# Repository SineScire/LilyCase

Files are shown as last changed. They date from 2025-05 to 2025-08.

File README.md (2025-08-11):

<a href="https://github.com/SineScire/LilyCase">LilyCase</a> © 2025 by <a href="https://github.com/SineScire">SineNomen</a> is licensed under <a href="https://creativecommons.org/licenses/by-nc-sa/4.0/">CC BY-NC-SA 4.0</a>

A tented case for the Lily58 with a gasket mounted switchplate. The Lily58 is originally created by [kata0510](https://github.com/kata0510), the case is made to use with the Lily58L created by [BenRoe](https://github.com/BenRoe).

There are multiple versions of the case
* With magnets: has holes for 6x2mm circular magnets for the palm rest and tag plate, wrist rest is recessed deeper for an additional plate.
* Without magnets: the wrist rest has to be attached with double sided tape or glue, magnet holes for the tag plate are still present.
* The files and directories with the "old" suffix are from the original case design, where the IO for the PCB is rerouted to bottom case housing.

And multiple versions of the gaskets:
* Soft: Switchplate flexes with the press of a single key
* Medium: Switchplate flexes with the press of multiple keys
* Hard: Switchplate hardly flexes with the press of multiple keys

Check out the manual [here](https://github.com/SineScire/LilyCase/blob/a8cb191af96765f0c5e2880e67829a860b818092/Manual.md)

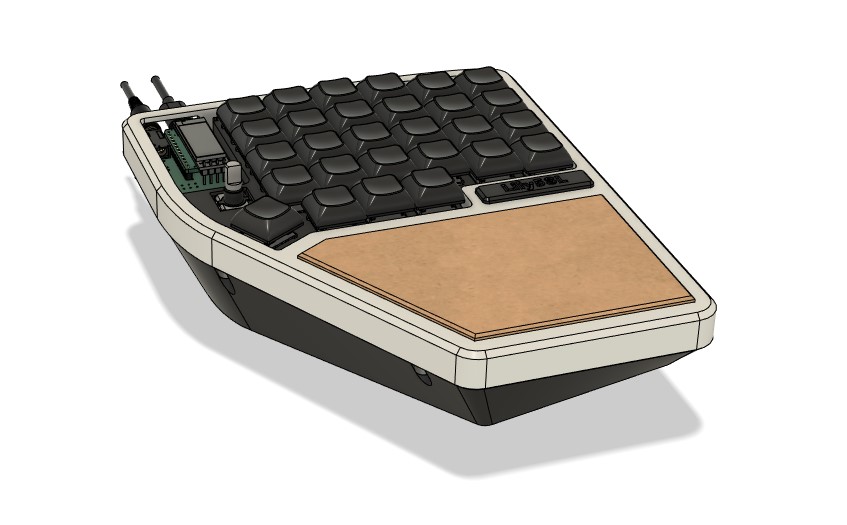
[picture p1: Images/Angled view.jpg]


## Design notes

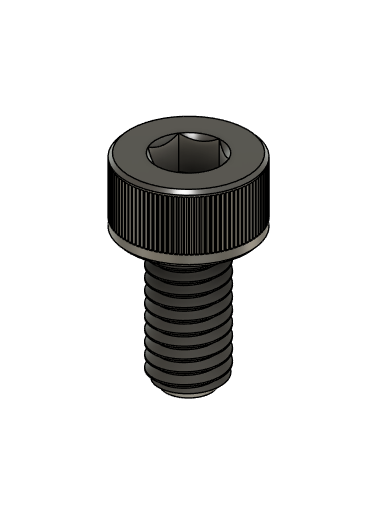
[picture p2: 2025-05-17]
Images/Fastner.png

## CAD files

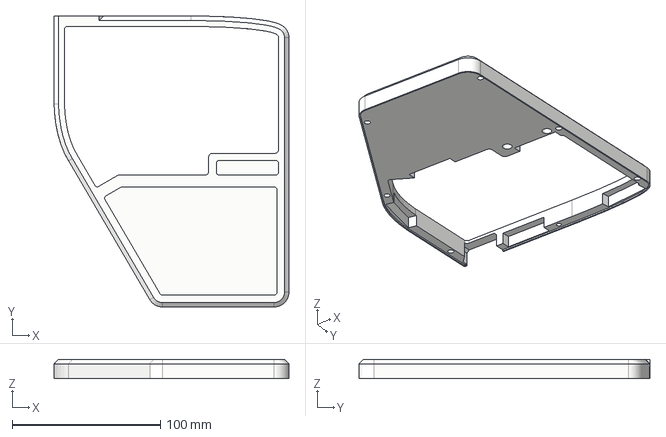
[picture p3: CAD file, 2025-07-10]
Files/TopHousing.step
158.5 x 196.4 x 13.0 mm

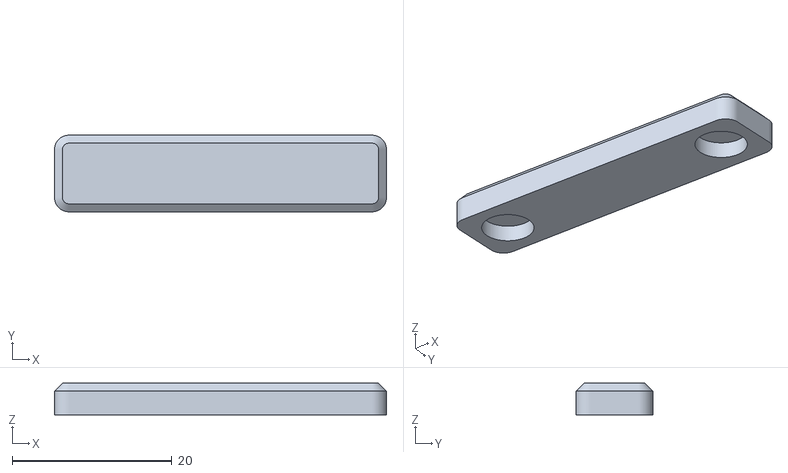
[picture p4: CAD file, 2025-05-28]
Files/TagPlateBlank.obj
41.6 x 9.60 x 4.00

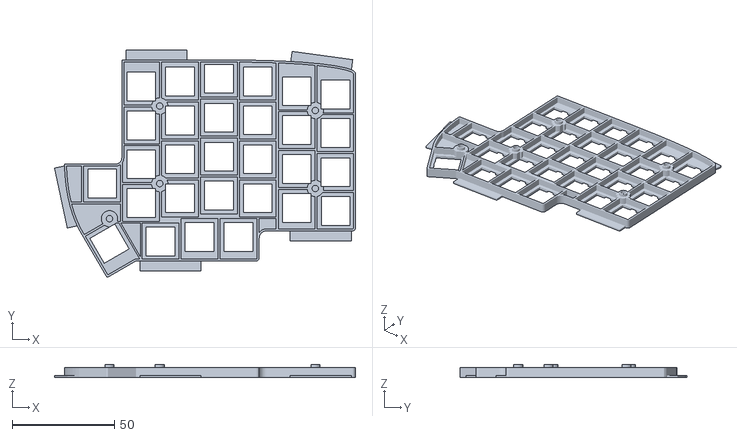
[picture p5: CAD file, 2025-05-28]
Files/SwitchPlateL.stl
147.4 x 111.3 x 6.51

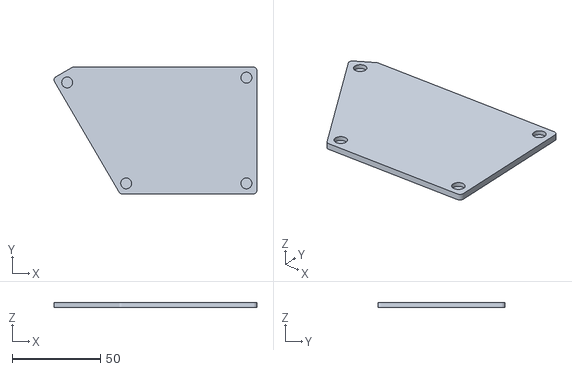
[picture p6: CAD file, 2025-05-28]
Files/WristPlateR.stl
115.2 x 72.0 x 3.00

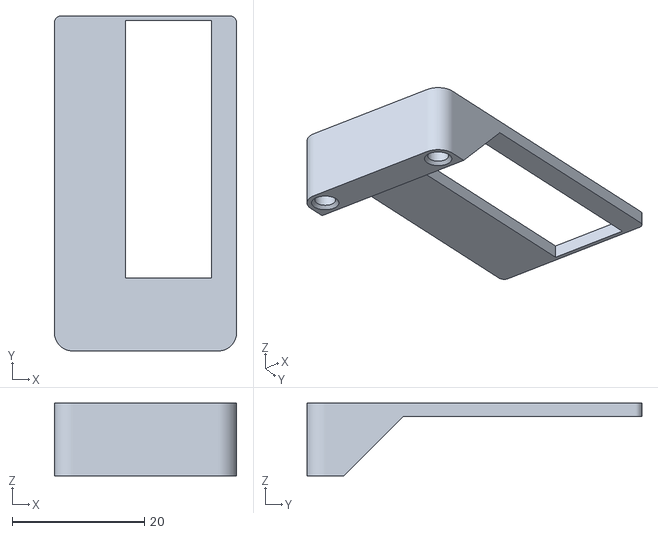
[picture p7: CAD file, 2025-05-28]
Files/Window R.stl
27.6 x 50.7 x 11.0

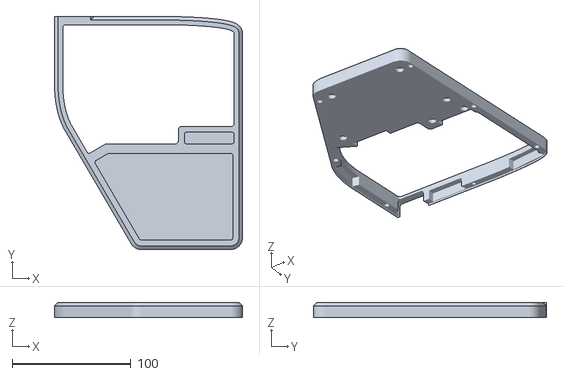
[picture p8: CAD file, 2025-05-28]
Files/TopHousingMagnetsR.stl
158.5 x 196.4 x 13.0

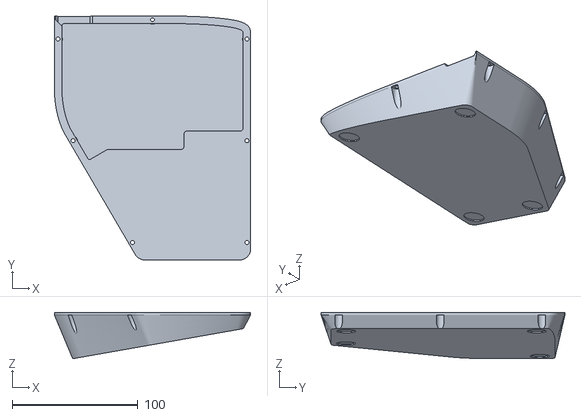
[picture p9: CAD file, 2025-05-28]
Files/BottomHousingR.stl
156.5 x 194.4 x 37.0

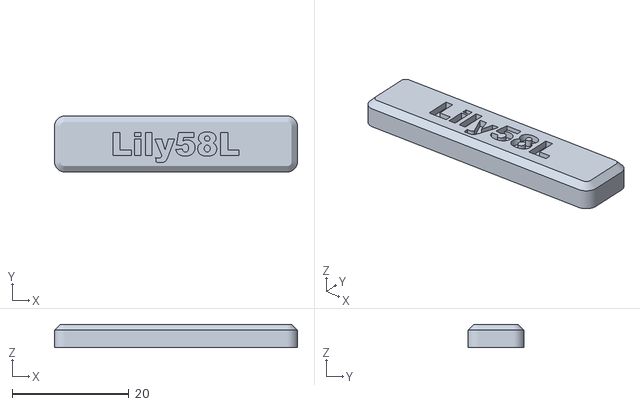
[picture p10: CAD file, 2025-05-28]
Files/TagPlate.stl
41.6 x 9.60 x 4.00

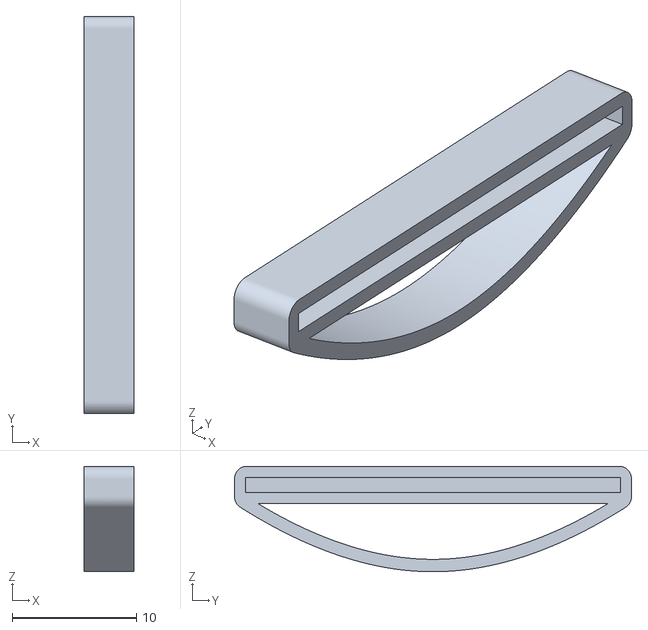
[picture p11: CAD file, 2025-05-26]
Files/GasketSoft.stl
4.00 x 32.0 x 8.50

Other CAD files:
Files/TopHousing2mmWristrestR.stl
Files/TopHousing2mmWristrestL.stl
Files/TopHousingR.stl
Files/Window L.stl
Files/TopHousingL.stl
Files/SwitchPlateR.stl
Files/WristPlateL.stl
Files/TopHousingMagnetsL.stl
Files/BottomHousingL.stl
Files/GasketHard.stl
Files/GasketMedium.stl
Files/Washer.stl
FillesOld/Bottom Housing.stl
FillesOld/Brace.stl
FillesOld/Switchplate.stl
FillesOld/Tag plate.stl
FillesOld/Top housing.stl
FillesOld/Wrist rest.stl

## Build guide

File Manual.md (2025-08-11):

## BOM
* For a complete set of two cases

| Part | Quantity | Description | Photo |
| ---- | --- | --- | ----- |
| Top housing | 2x | 3D printed mirrored part |  |
| Bottom housing | 2x | 3D printed mirrored part |  |
| Switchplate | 2x | 3D printed mirrored part |  |
| Tag plate | 2x | 3D printed |  |
| Washer | 10x | 3D printed part to fasten the PCB to the switchplate |  |
| Gasket | 10x | 3D printed part from a flexible type of filament with the hardness around 95A |  |
| Wristrest plate | 2x | 3D printed part for the magnet version |  |
| m2x4mm threaded insert | 10x | Brass inserts for the switchplate |  |
| m3x5mm threaded insert | 14x | Brass inserts for the top housing |  |
| m2x5mm socket head screw | 10x | To mount the PCB to the switch plate |  |
| m3x6mm socket head screw | 14x | To mount the bottom to the top housing |  |
| Stick on rubber feet | 8x | 15mm diameter, 2mm height |  |
| Wristrest material | 2x | cork/neopreme or a different prefered material, minimum size 12x8cm and 4mm thick |  |
| Assembled Lily58 PCB | 2x | Used when inerting the brass inserts |  |
| Soldering iron | 1x | For inserting the threaded inserts |  |
| Tweezers | 1x | For holding the threaded inserts |  |
| Precision knife | 1x | For cutting the palm rest material |  |
| Double sided tape | 1x | To adhere the palm rest material to the top housing and to adhere the tagplate |  |
| Glue | 1x | To glue the magnets for the magnet version |  |

## 1. Printing the parts
1. Before printing the parts, decide if you want to adhere the wristrest directly to the top housing with double sided tape, or use the magnetized version. The files named 'TopHousingMagnets' use magnets to keep the wristrest in place, the files named 'TopHousing2mmWristrest' uses a 2mm deep wristrest cutout to adhere your preferred wristrest material in with double sided tape.
2. The gaskets are printed with a flexible type filament, they were made using a 95A hardness filament. 
* Suggested printing orientation for the parts with supports enabled, showing the right hand side case only.

| Top housing | Bottom housing | Switchplate |
| --- | --- | --- |
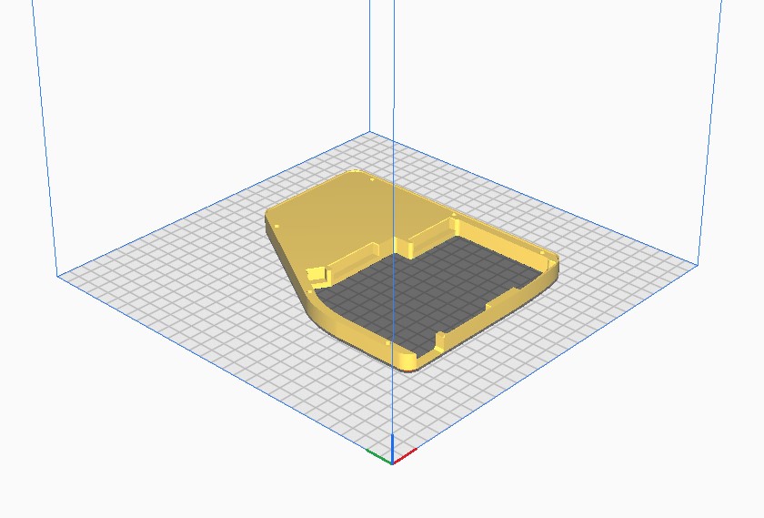
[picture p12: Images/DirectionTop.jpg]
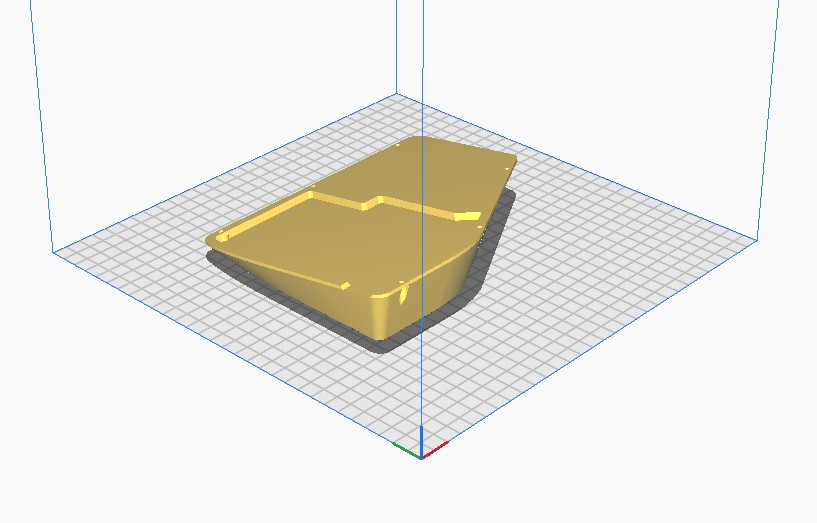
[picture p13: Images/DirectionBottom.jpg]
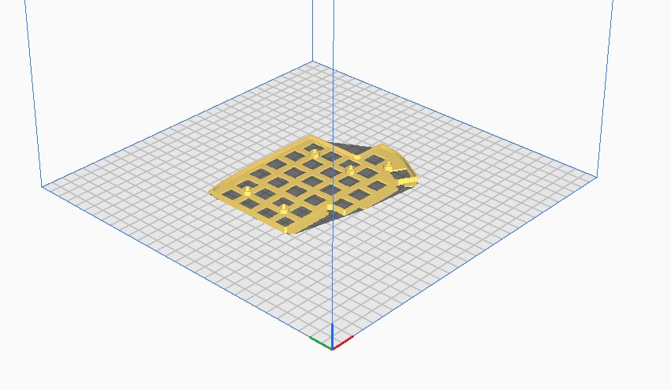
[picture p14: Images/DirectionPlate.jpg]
|  |  |  |

| Washer | Tag plate | Gasket |
| --- | --- | --- |
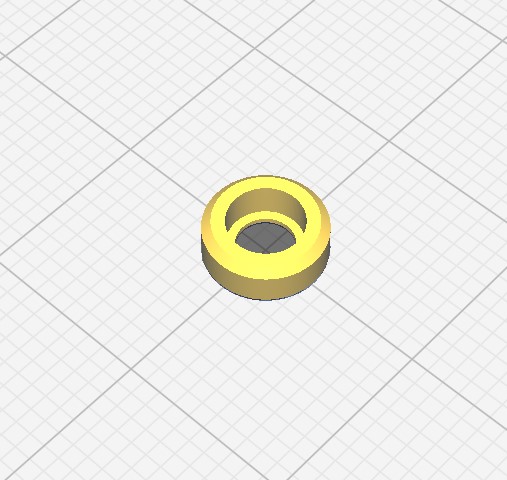
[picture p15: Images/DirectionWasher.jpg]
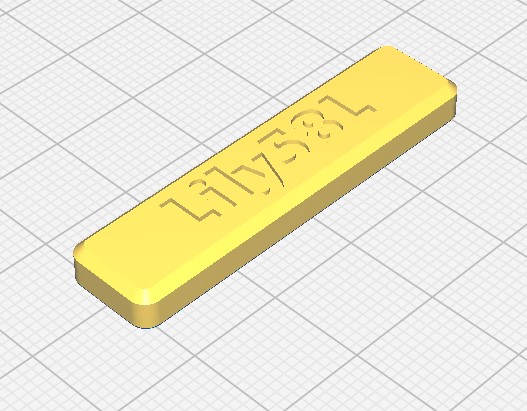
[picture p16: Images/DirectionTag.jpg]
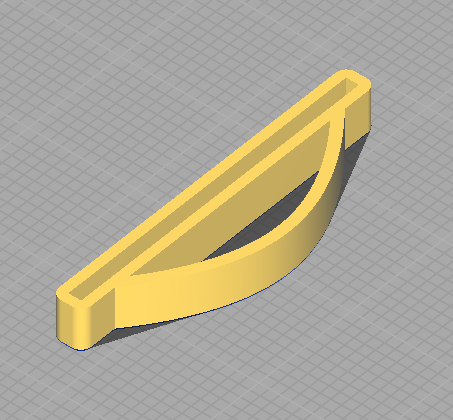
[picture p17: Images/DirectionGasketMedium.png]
|  |  |  |

### Preparing the switchplate
* Parts needed: Switchplate, Washers, m2x4mm threaded inserts, m2x5mm socket head screws, soldering iron.
1. Place the switchplace with the standoffs facing up, in the same suggested orientation it was printed in and place the PCB onto the switchplate as shown in the image below.
2. Using a soldering iron, insert the five m2x4mm threaded inserts into the switchplate at the blue highlighted spots in the image below.
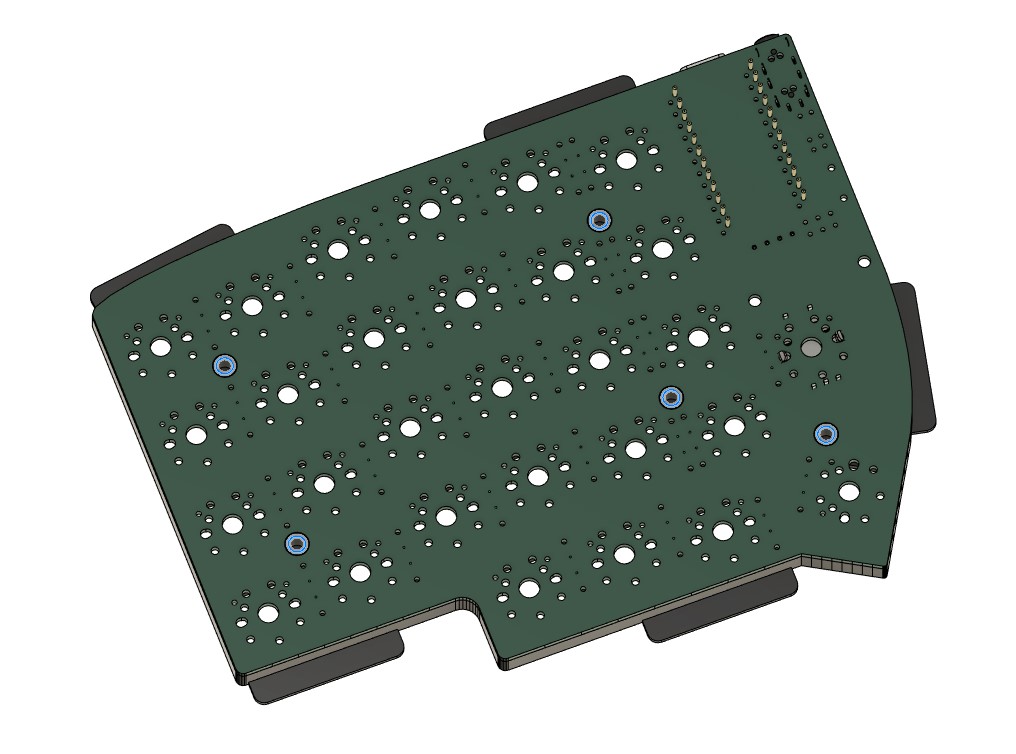
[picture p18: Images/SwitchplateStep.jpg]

3. After having cooled down use the washers and the m2x5mm socket head screws to fasten the PCB to the switchplate.
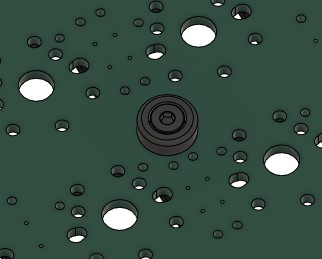
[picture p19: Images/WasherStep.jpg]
 
4. Assemble the switchplate/PCB further with your choise of switches and keycaps.

### Preparing the top housing
* Parts needed: Top housing, m3x5mm threaded inserts, soldering iron, palm rest material, tamplet, precision knife, double sided tape.
1. Place the top housing facing down and using a soldering iron, insert the six m3x5mm threaded inserts into the top housing shown at the blue highlighted spots in the image below.
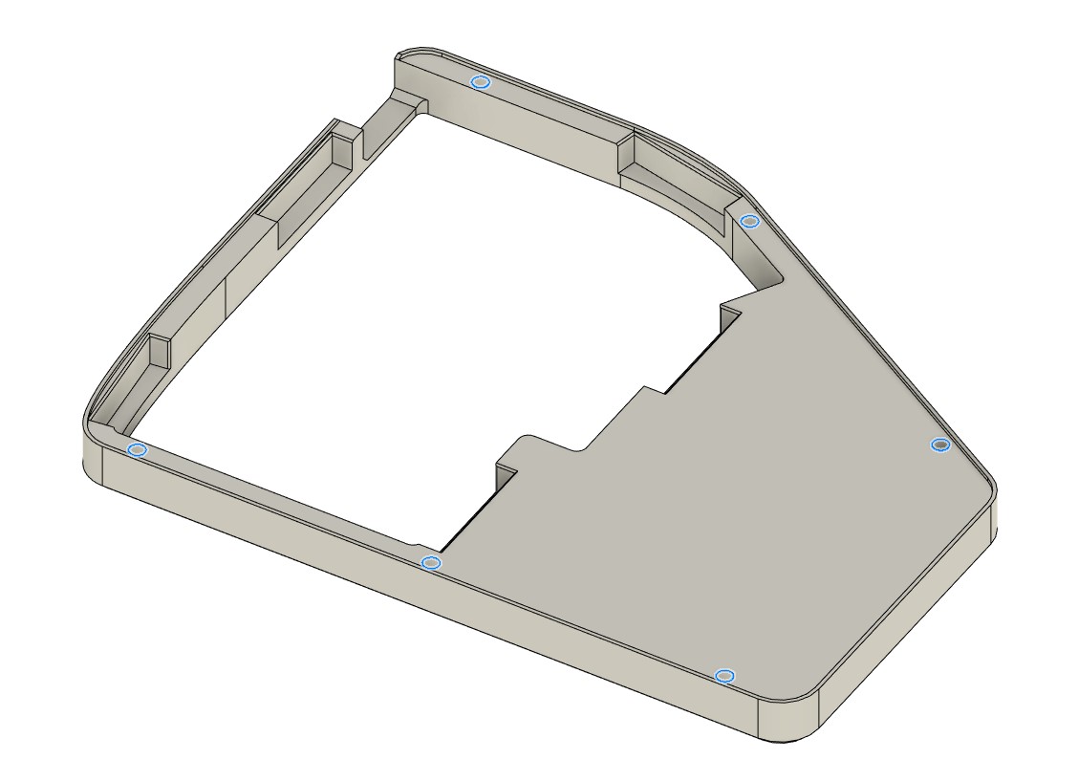
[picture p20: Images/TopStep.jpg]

2. Use the template to cut the palm rest material with the precision knife, the cut out palm rest can be adhered using double sided tape to the top housing or a different preferred method.
3. The tag plate can also be adhered in its place using double sided tape, or four 6x2mm magnets can be glued in place if so desired.

### Assembling the case
* Parts needed: Assembled top housing, assembled switchplate/PCB, gaskets, twelve m3x6mm socket head screws.
1. Slide the gaskets onto the lips of the switchplate as shown in the image below.
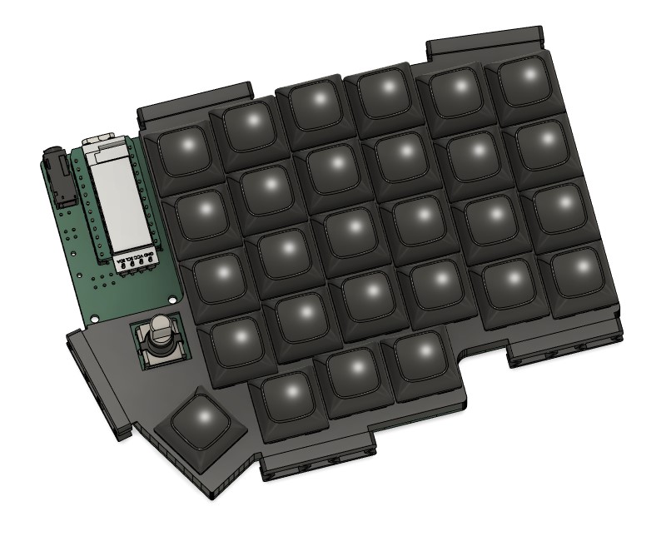
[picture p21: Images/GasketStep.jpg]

2. Place the switchplate on the bottom housing and place the top housing on top, sandwiching the gaskets and switchplate in between. The switchplate and gaskets should align them selves and the lip of the top housing should sit around the edge of the bottom housing.
3. Use six m3x6mm socket head screws to fasten the case together, completing one side of the case! Repeat these steps for the other side of the case.



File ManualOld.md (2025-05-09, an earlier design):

 <p xmlns:cc="http://creativecommons.org/ns#" >This work is licensed under <a href="https://creativecommons.org/licenses/by-nc-nd/4.0/?ref=chooser-v1" target="_blank" rel="license noopener noreferrer" style="display:inline-block;">CC BY-NC-ND 4.0</a></p> 

A case for the lily58 with a suspended switchplate. The Lily58 is originally created by [kata0510](https://github.com/kata0510), the case is made to use with the Lily58L created by [BenRoe](https://github.com/BenRoe).

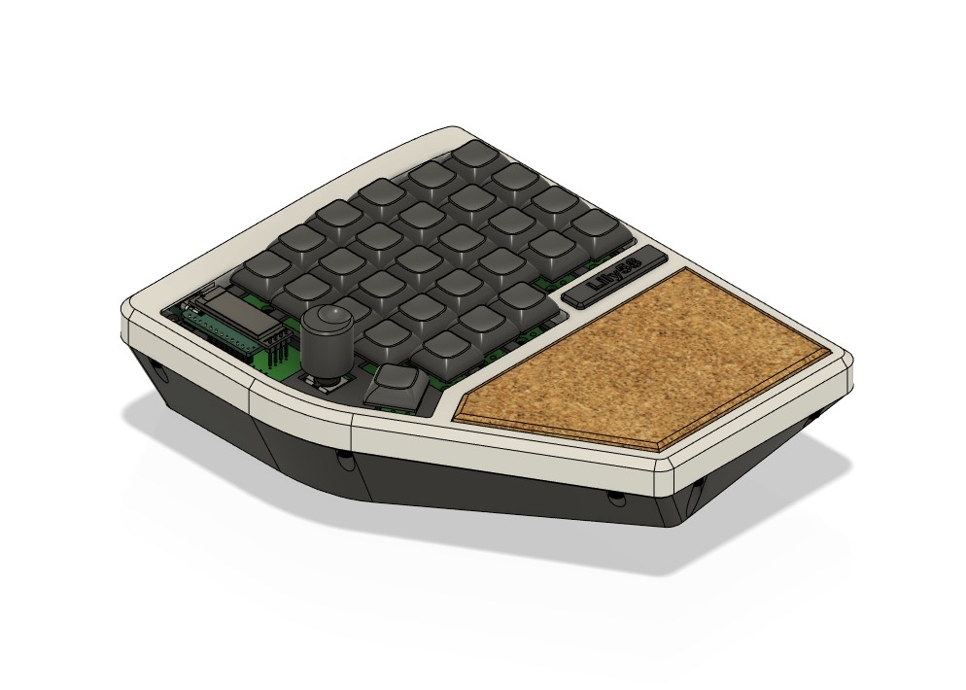
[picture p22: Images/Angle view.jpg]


## BOM for two cases for a complete keyboard set.

| Part | Quantity for one side | Description | Photo |
| ---- | --- | --- | --- |
| Top housing | 2x | 3D Printed, one print needs to be mirrored |
| Bottom housing | 2x | 3D Printed, one print needs to be mirrored |
| Switchplate | 2x | 3D Printed, one print needs to be mirrored |
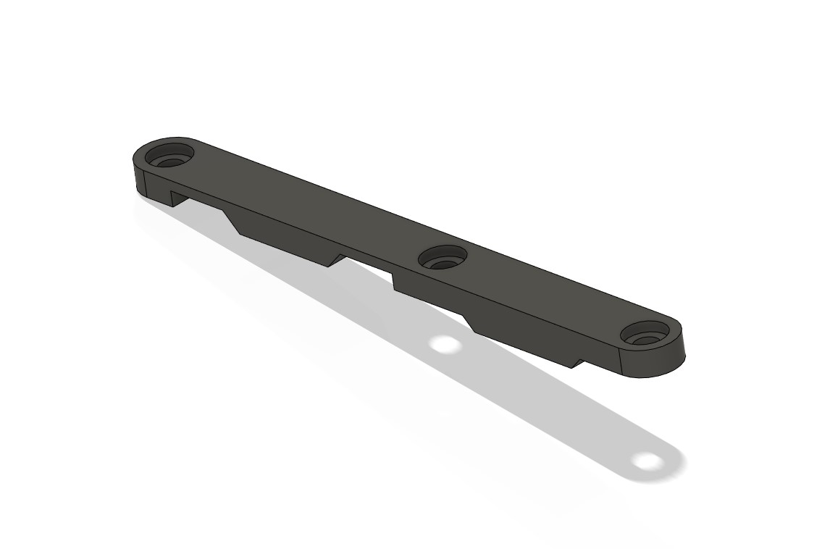
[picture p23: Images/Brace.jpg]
| IO Brace | 2x | 3D Printed, holds down the USB and TRRS breakout board down in the bottom housing |  |
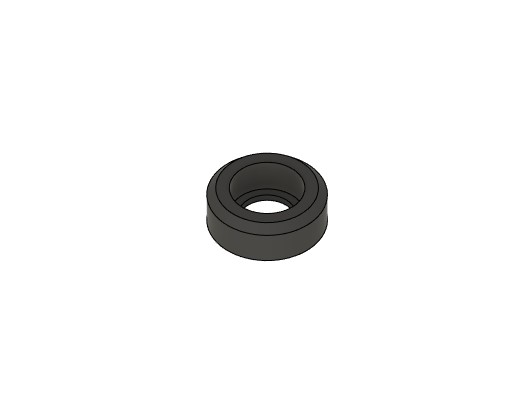
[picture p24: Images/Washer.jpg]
| Washers | 10x | 3D Printed, for the screws connecting the switchplate to the PCB |  |
| m2x5mm Socket Head Screw | 26x | For the Switchplate, Top housing and IO Brace |
| m3x5mm Socket Head Screw | 22x | Connects the Bottom housing to the Top housing |
| m2x4mm Brass Insert | 26x | For the Switchplate, Top housing and Bottom housing |
| m3x5mm Brass Insert | 22x | For the Top housing, to connect with Bottom housing |
| Gasket foam | 6x | In the length of 2x 20mm, 2x 50mm and 2x 70mm, the width of 8mm |
| TRRS plug | 2x | Connects to the PCB |
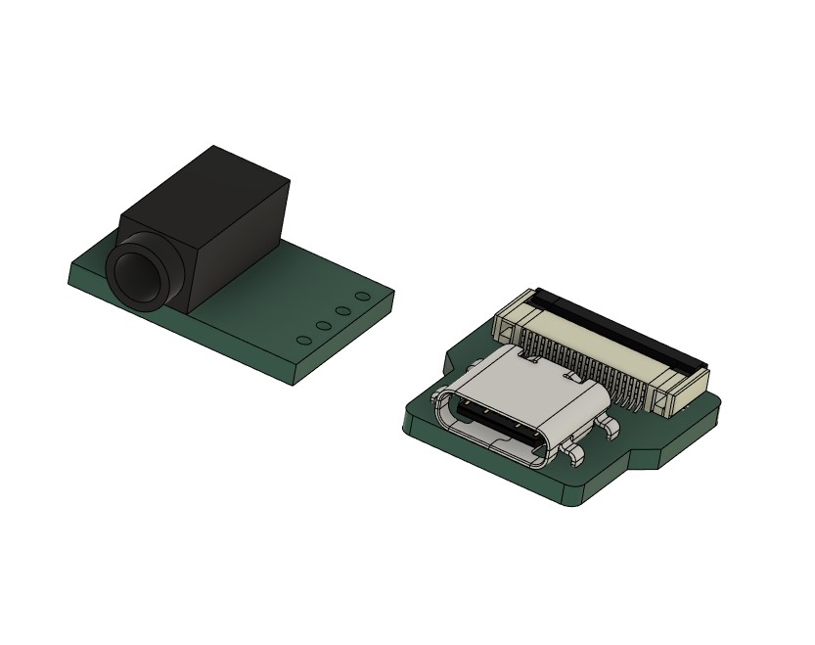
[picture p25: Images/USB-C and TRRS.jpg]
| TRRS Breakout board | 2x | Mounts to the Bottom housing for IO access |  |
| Wire | 8x | Around 10cm of wire to connect the TRRS plug and breakout board |
| Shrinkwrap | 2x | For the TRRS plug. |
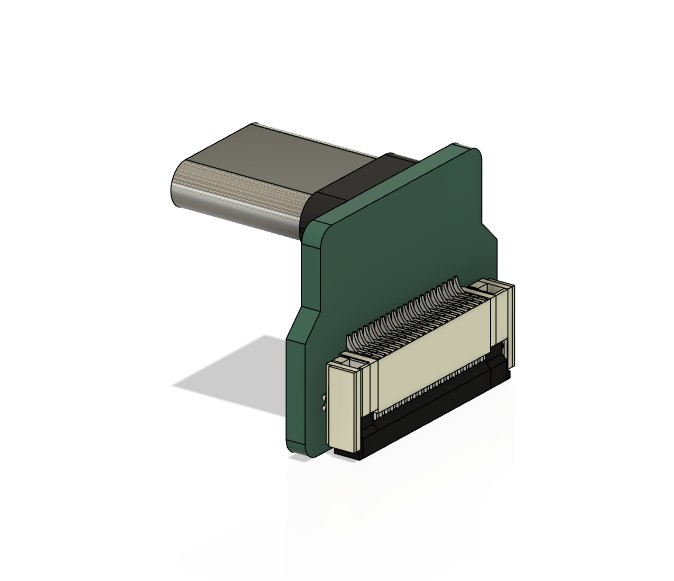
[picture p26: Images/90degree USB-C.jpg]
| 90° USB-C Ribbon Connector | 2x | Connects to the PCB. Part D2, can be ordered [here](https://www.aliexpress.com/item/1005003785689812.html?) | 
| USB-C Ribbon Connector | 2x | Mounts to the Bottom housing for IO access. Part D4, can be ordered [here](https://www.aliexpress.com/item/1005003785689812.html?) | See TRRS Breakout board |
| Ribbon cable | 2x | Connects the two USB-C Boards. 10cm FFC, can be ordered [here](https://www.aliexpress.com/item/1005003785689812.html?) |
| Stick on feet | 8x |
| Lily58 PCB | 2x |
| Soldering equipment | 1x | To insert the brass inserts into the case parts and to solder to TRRS cables |
| Multimeter | 1x | To check the continuity for soldering the TRRS cable |
| Small metal object with a flat surface | 1x | Optional but useful, to align and straighten the brass insert after inserting it |
| Tweezers to hold brass inserts | 1x |

Because the switchplate is able to flex, this case requires two cables to be routed inside from the Lily58 PCB to the bottom housing where the USB-C port and TRRS port will be. This requires making a TRRS cable and ordering parts for a USB-C ribbon cable.
The photos are showing the right hand side.

### Assembly

#### Preparing the switchplate
* Parts needed: Switchplate, PCB, 5x m2x4 brass inserts, 5x washers, 5x m2x5mm Socket head screws, dampening foam.
1. Place the switchplate down with the standoffs facing up and place the Lily58 PCB on top as show in the image, the PCB prevents excess deformation of the Switchplate when inserting the brass inserts and ensures a proper fit afterwards.
2. Insert the 5 m2x4mm Brass Inserts into the blue hightlighted openings.
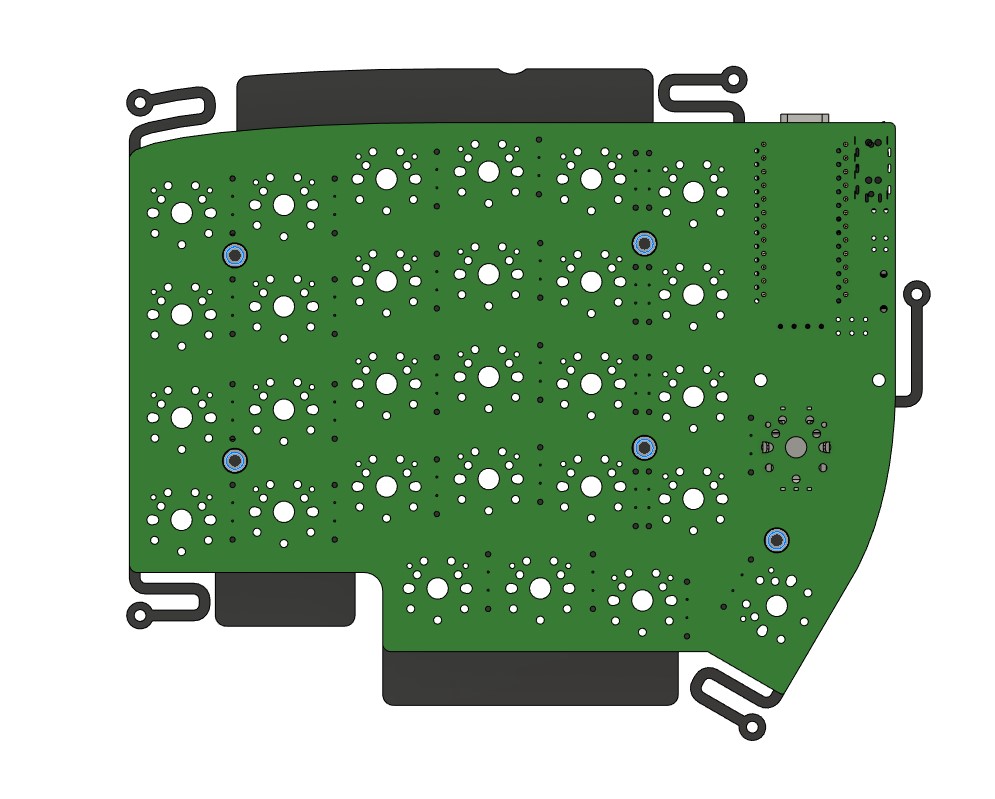
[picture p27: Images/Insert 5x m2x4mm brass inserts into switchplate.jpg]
Switchplate

3. Using the 5 washers and 5 m2x5mm Socket head screws, the switchplate can be mounted onto the PCB.
4. Apply the dampening foam to the areas highlighted in blue.
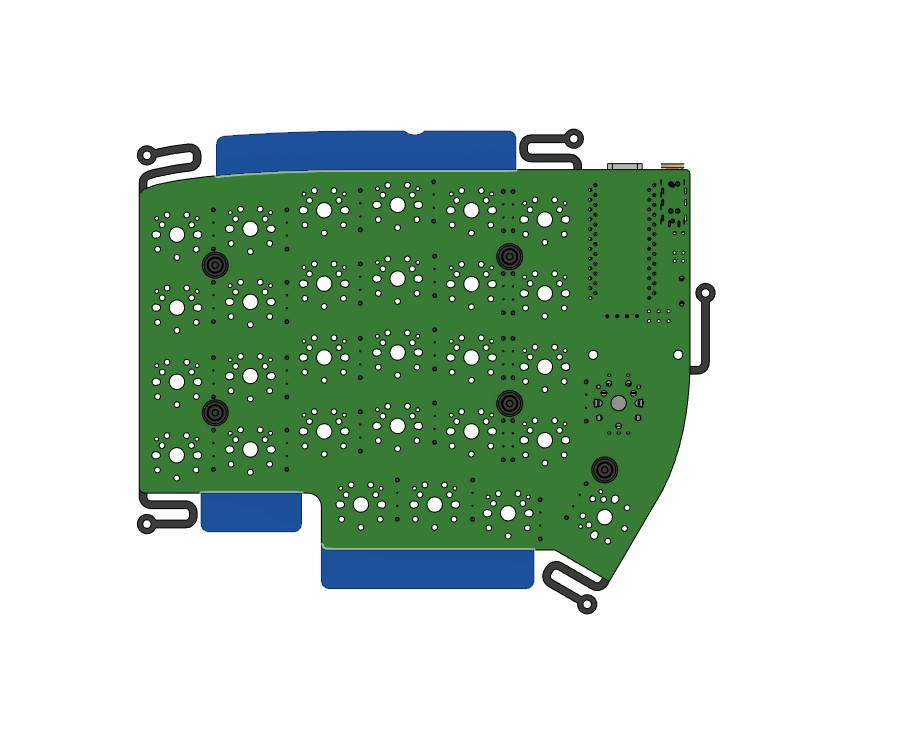
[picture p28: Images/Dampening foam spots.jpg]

5. Assemble the PCB/Switchplate with the desired switches and keycaps, resulting in an assembly looking like this.
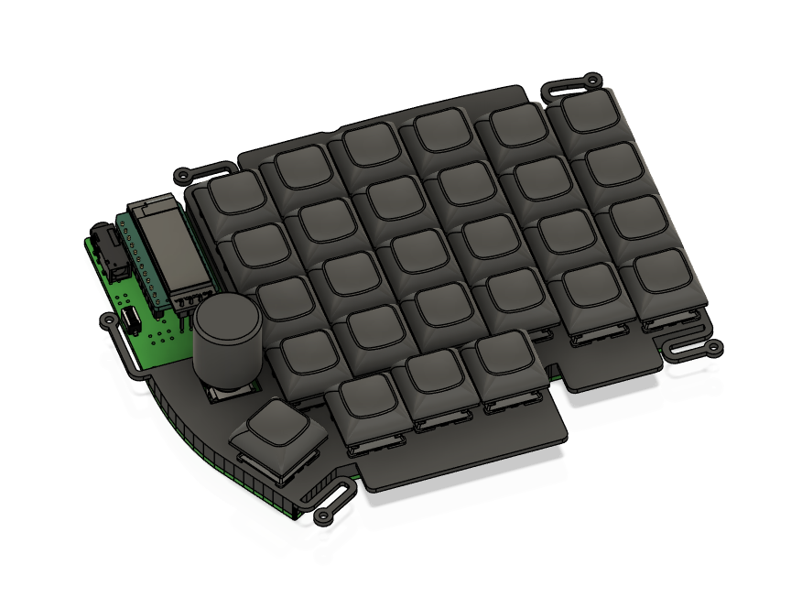
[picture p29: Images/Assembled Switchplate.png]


#### Soldering the TRRS cable and assembling the USB-C Flex cable
* Parts needed: TRRS jack, TRRS breakout board, USB-C 90° flex connector, USB-C flex connector, 4x wire.
1. Assemble the USB-C connector by sliding back the black locking mechanism on the ribbon connector and insert the ribbon cable with the contacts facing away from the PCB, resulting in a cable looking like this.
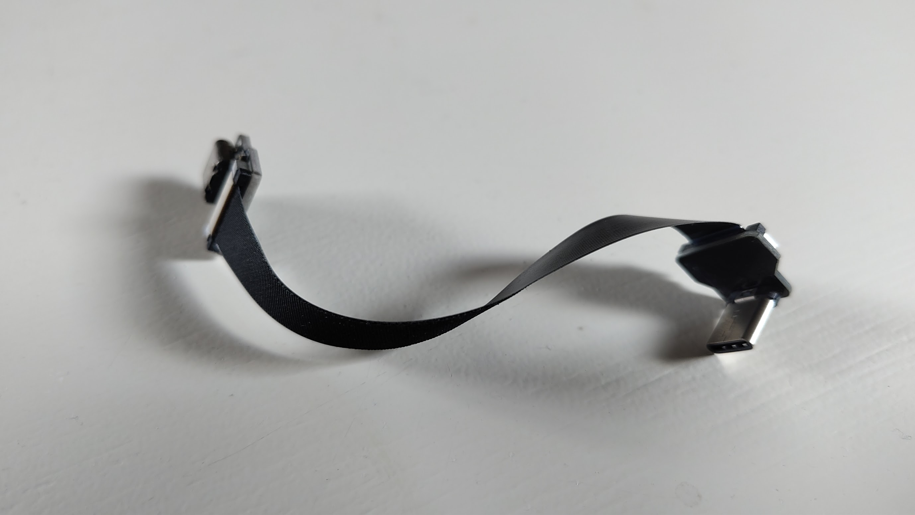
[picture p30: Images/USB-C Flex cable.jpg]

2. Solder the wires to the solder points of the TRRS plug and apply a 90° bend for clearance with the case.
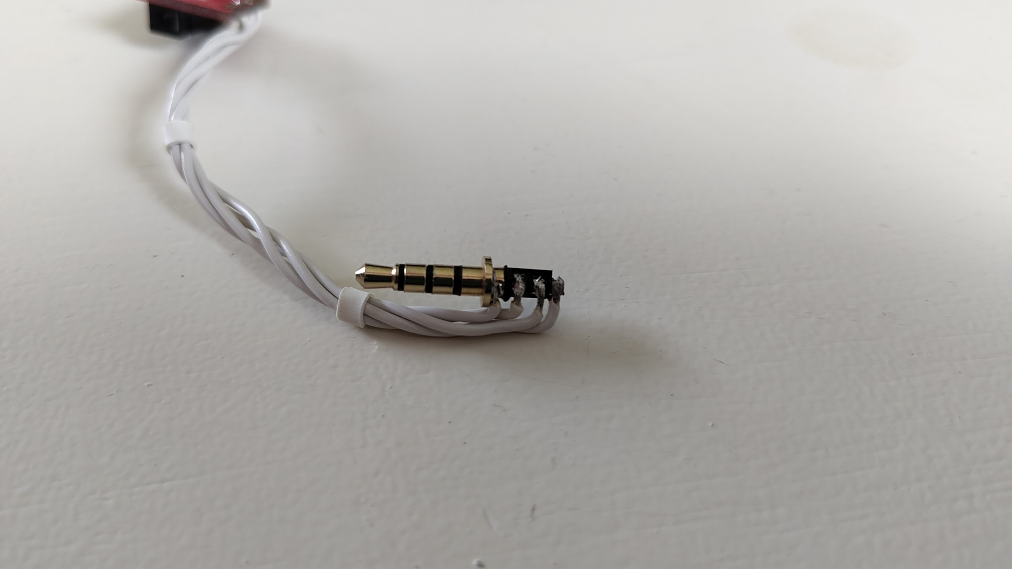
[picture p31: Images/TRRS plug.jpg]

3. Solder the corresponding wires on the TRRS plug to the breakoutboard, keeping note of the ring closest to the tip and to the sleeve.
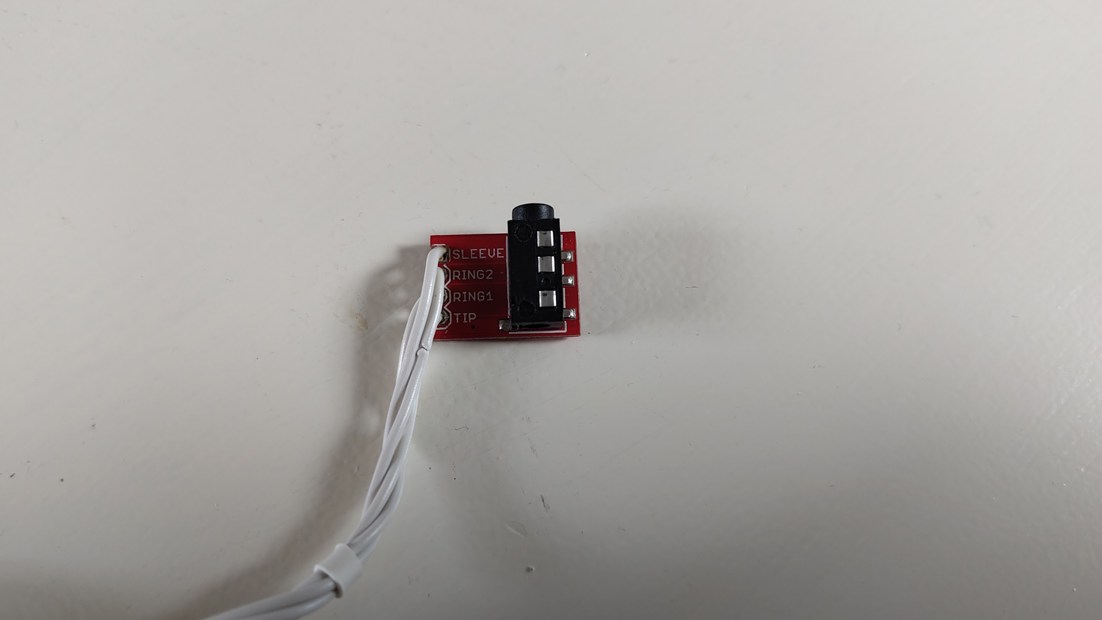
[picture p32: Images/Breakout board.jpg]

4. Apply some heat-shrink to the end of the TRRS plug, the resulting cable should look something like this.
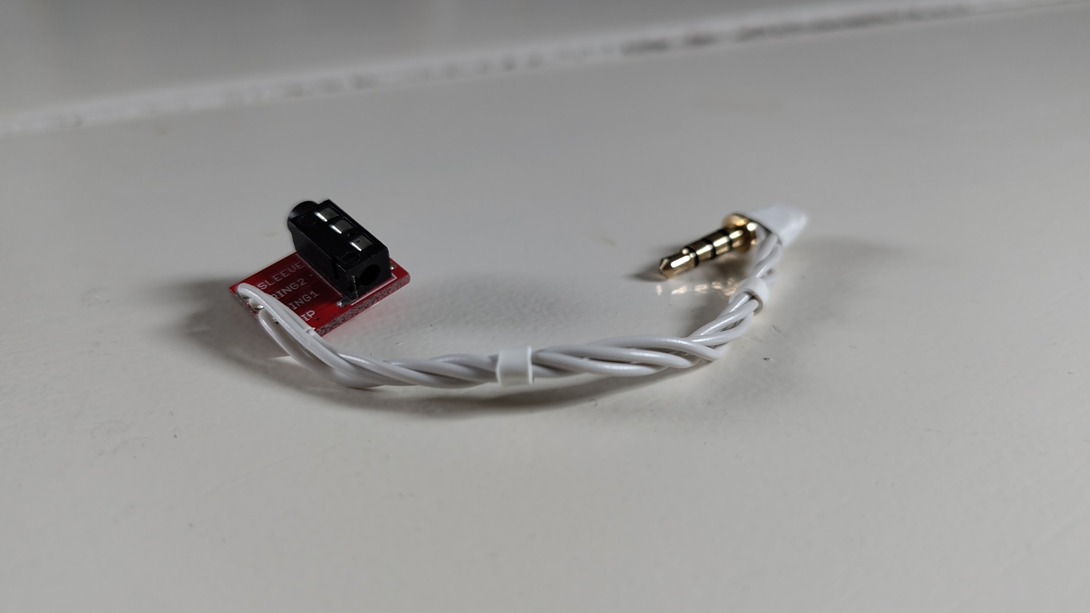
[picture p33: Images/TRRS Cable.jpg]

5. Plug the 90° USB-C board and the TRRS plug into the PCB before assembling it with the top housing.

#### Preparing the Top housing
* Parts needed: Top housing, 5x m2x4mm brass inserts, 11x m3x5mm Socket head screws, 5x m2x5mm Socket head screws.
1. Place the housing facing down.
2. Insert the 5 m2x4mm brass inserts in the opening shown in the blue highlights in the image below.
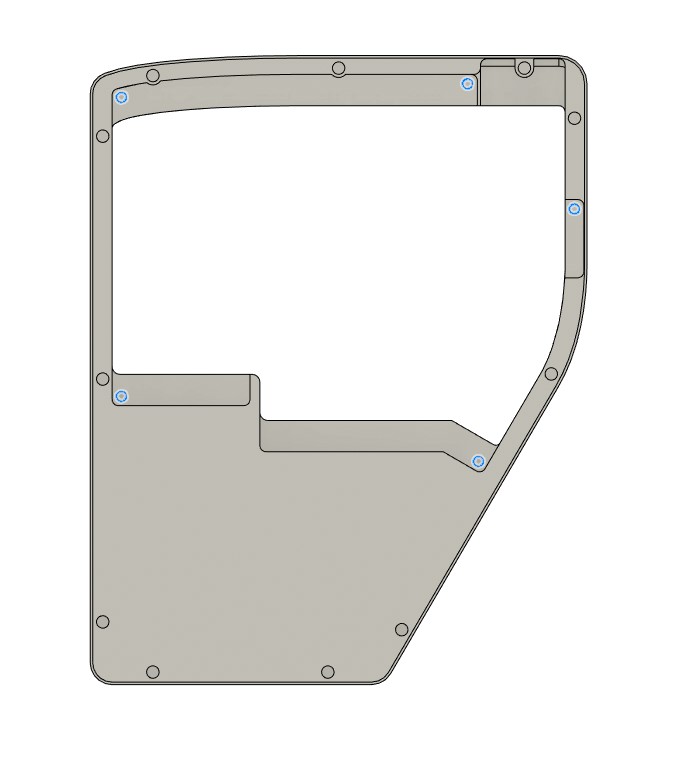
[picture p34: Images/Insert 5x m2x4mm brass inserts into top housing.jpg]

3. Insert the 11 m3x5mm brass inserts around the outer edge shown in the blue highlights in the image below.
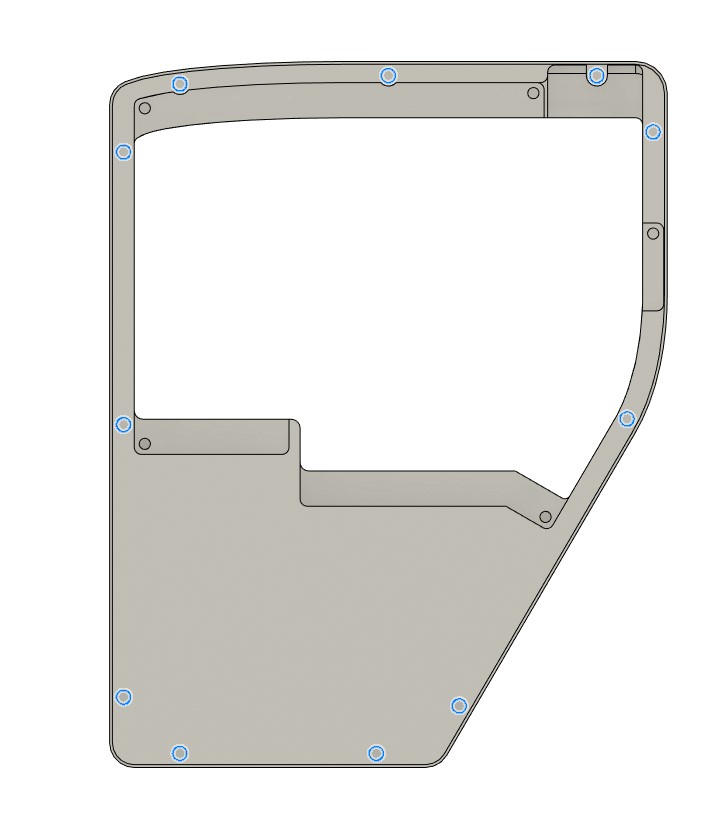
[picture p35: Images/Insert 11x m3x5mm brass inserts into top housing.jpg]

4. If desired, the assembled PCB with switches, keycaps, 90° USB-C connector and TRRS jack can be mounted to the top housing.

#### Preparing the Bottom housing
* Parts needed: Bottom housing, IO Brace, 3x m2x4mm brass inserts, 3x m2x5mm Socket head screws, 4x stick on feet.
1. Insert the 3 m2x4mm brass inserts in the openings show in the blue highlights in the image below.
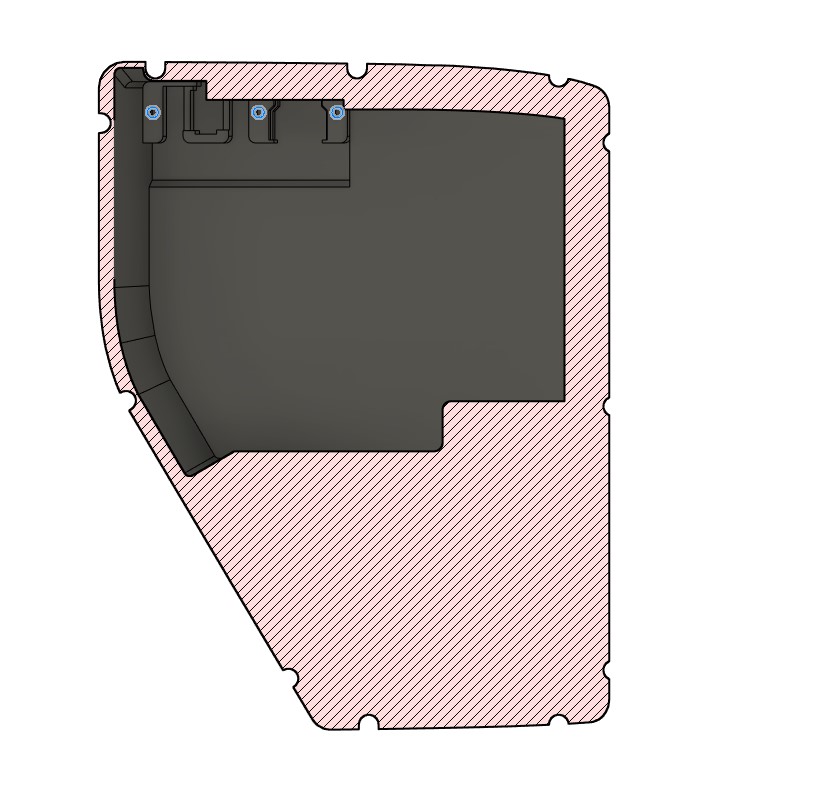
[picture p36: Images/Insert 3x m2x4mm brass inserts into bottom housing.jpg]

2. Place the top housing with the keyboard facing down above the bottom housing to have the shortest path for the cables to the bottom housing.
3. The TRRS breakout board and USB-C board can be placed in the bottom housing and held down with the brace using 3x m2x5mm socket head screws, note that the thicker part of the brace holds down the USB-C PCB.
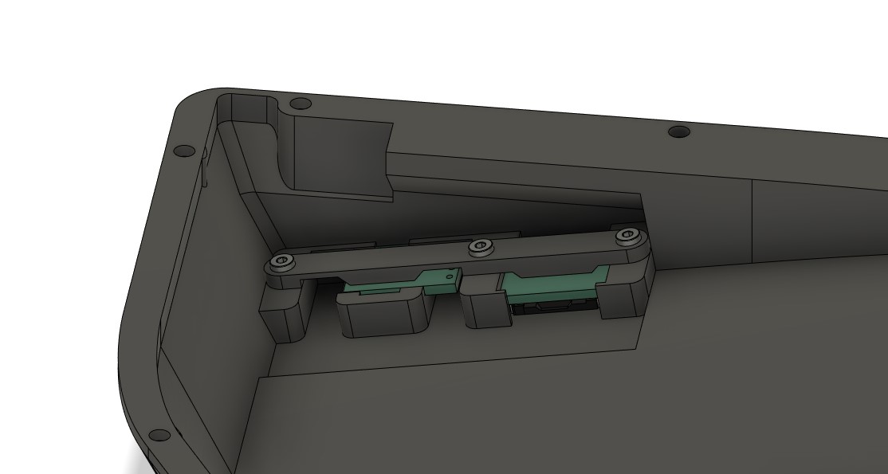
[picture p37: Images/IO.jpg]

4. The top housing of the case can be placed on the bottom housing, make sure not to put too much tension on the cables. Use the 11x m3x5mm socket head bolts to assemble the case.

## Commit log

2025-05-15 Rename Bottom Housing.stl to Bottom Housing.stl
    [Bottom Housing.stl]
2025-05-15 Rename Assembled Switchplate.png to Assembled Switchplate.png
2025-05-26 Rename Bottom Housing L.stl to BottomHousingL.stl
    [BottomHousingL.stl]
2025-05-26 Rename Bottom Housing R.stl to BottomHousingR.stl
    [BottomHousingR.stl]
2025-05-26 Rename Switchplate L.stl to SwitchplateL.stl
    [SwitchplateL.stl]
2025-05-26 Rename Switchplate R.stl to SwitchplateR.stl
    [SwitchplateR.stl]
2025-05-26 Rename Tag Plate.stl to TagPlate.stl
    [TagPlate.stl]
2025-05-26 Rename Top Housing L.stl to TopHousingL.stl
    [TopHousingL.stl]
2025-05-26 Rename Top Housing R.stl to TopHousingR.stl
    [TopHousingR.stl]
